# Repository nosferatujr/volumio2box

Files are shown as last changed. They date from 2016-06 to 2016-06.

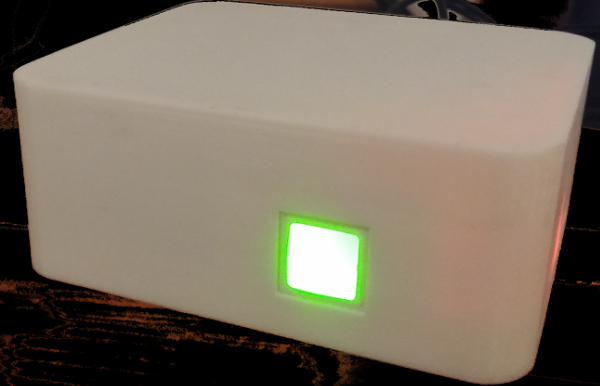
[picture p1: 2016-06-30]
photo.jpg

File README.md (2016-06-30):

PRinted box for RPi2 | HiFiBerry DAC+ | Proper poweroff (GPIO)  

You can find openscad files for the box on the BOX folder  
The Eagle PCB files on PCB folder  
The Pic microcontroller files, including the HEX on PowerController_PIC folder  
The off_button.py on the python folder. This file contain instruictions to be copied on the RPi, install dependencies, and run on the startup.  

    TO2:
    include photos for the conexion of all pcb inside the box
    put all this in a volumio plugin (pin configurable)

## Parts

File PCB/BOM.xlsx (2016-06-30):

Part | Value | Device | Package | Description | MF | OC_FARNELL | OC_NEWARK
C1 | 100n | C-EUC0805 | C0805 | CAPACITOR, European symbol
IC1 | 12F629 | PIC12F629SN | SO-08 | Data Sheet 8-Pin FLASH-Based 8-Bit CMOS Microcontrollers | MICROCHIP | 9759000 | 61K3433
JP1 | USB-RECEPTABLE | USB-RECEPTABLE | FCI-10103594-0001LF | USB Receptable |  | 2293752(farnell) (http://es.farnell.com/jsp/search/productdetail.jsp?CMP=i-ddd7-00001003&sku=2293752)
Q1, Q2 | AP4435GH | IRFR5305 | D-PAK_TO252AA | HEXFET Power MOSFET
R1, R3, R4, R7 | 2k2 | R-EU_R0805 | R0805 | RESISTOR, European symbol
R2 | 330 OHMIOS | R-EU_R0805 | R0805 | RESISTOR, European symbol
R5, R6 | 4k7 | R-EU_R0805 | R0805 | RESISTOR, European symbol
S1 | RF15L2 | RF15L2 | RF15L2 | RAFI SWITCH
SV1 |  | MA05-1 | FE05-1 | PINES MACHO |  | unknown | unknown
SV2 |  | MA04-1 | MA04-1 | PINES MACHO ACODADO |  | unknown | unknown
X1, X2 | 22-23-2021 | MA02-1 | 22-23-2021 | PINES MACHO ACODADO | MOLEX | 1462926 | 25C3832
T1, T2, T3 | BC848 | BC848 | SOT23 | NPN TRANSISTOR

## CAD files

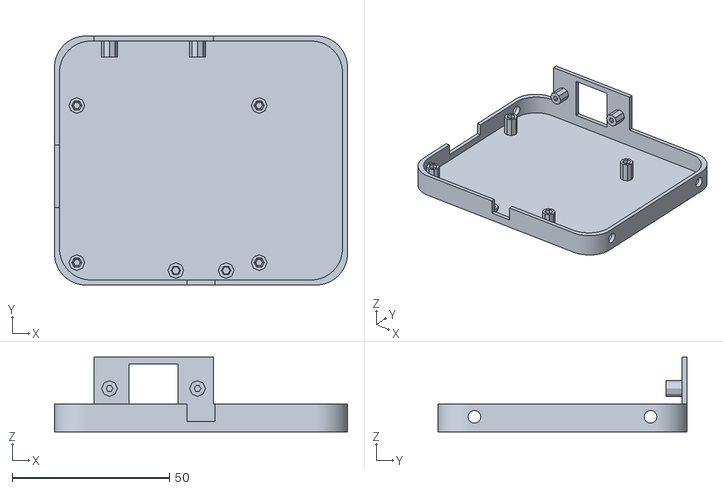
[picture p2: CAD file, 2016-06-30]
BOX/volumio_base.stl
93.2 x 79.2 x 23.8

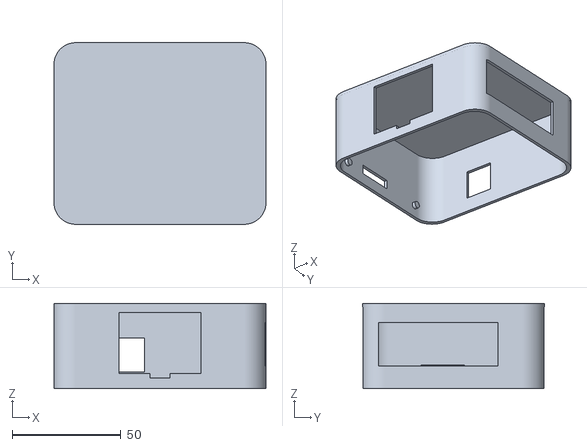
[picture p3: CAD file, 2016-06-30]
BOX/volumio_cover.stl
97.7 x 83.7 x 39.3

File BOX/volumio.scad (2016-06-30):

module fillet(r, h) {
        difference() {
            cube([r + 0.01, r + 0.01, h], center = true);
            translate([r/2, r/2, 0])
                cylinder(r = r, h = h + 1, $fn = 200,center = true);
        }
}

module torreta(h){
    translate([0,0 , h/2-.2 ])difference(){
  cylinder(  h-1.5 , 2.5,  2.5 ,true); 
  cylinder(  h , 1,  1.7 ,true);  
}
}

module soporte_pi (){
    
	translate([29, 25, 0])  torreta(9); 
	translate([-29, -25,  0 ])  torreta(9);  
	translate([-29, 25,  0])  torreta(9); 
	translate([29, -25,  0 ])  torreta(9);  
    
}
module torreta_puls(){
   	rotate([270,0,0]) translate([14, 0, 0])  torreta(7); 
	rotate([270,0,0]) translate([-14, 0,  0 ])  torreta(7);   
    
}

module soporte_usb (){
  translate([8, 0, 0 ])  torreta(3);
  translate([-8, 0, 0 ])  torreta(3);
}



module perfil(li,wi,h,t,r,tip){
    le=li+t*2;
    we=wi+t*2;
    
    module round(p){
        if (p==0){
        translate ([le/2-5,   we/2-5 ,0])rotate([180,180,0])fillet(r, h+1);
        translate ([(le/2*-1)+5,we/2-5,0])rotate([180,0,0])fillet(r, h+1);
        translate ([le/2-5,   (we/2*-1)+5,0])rotate([0,180,0])fillet(r, h+1);
        translate ([(le/2*-1)+5,(we/2*-1)+5,0])rotate([0,0,0])fillet(r, h+1);
        }
        else{     
        translate ([li/2-5,   wi/2-5 ,0])rotate([180,180,0])fillet(r, h+1);
        translate ([(li/2*-1)+5,wi/2-5,0])rotate([180,0,0])fillet(r, h+1);
        translate ([li/2-5,   (wi/2*-1)+5,0])rotate([0,180,0])fillet(r, h+1);
        translate ([(li/2*-1)+5,(wi/2*-1)+5,0])rotate([0,0,0])fillet(r, h+1);    
        }

}

    difference(){
    difference(){
    cube([le , we, h ] ,true );
    round(0);
    }
    if (tip!=1){
    difference(){
    cube([li , wi, h+1 ] ,true );
        round(1);
        }
    }
    }
}

module sop_pul(){
    difference(){
    cube([38,1.6,,20], center = true);  
     cube([15.5, 5,15.5  ] ,true );  
        }
     translate([0, -6.5, 0 ])torreta_puls();
    }

//tapa inferior
module tapa_i(){
  
 perfil(90,76,1.6,1.6,10,1);

 difference(){
 translate([0,0,4])perfil(90,76,8,1.6,10,0);
 translate([0, -40, 6 ])  cube([9,9,7], center = true);   
   rotate([0,90,0])  translate([-4,28,0]) cylinder(  105 , 2,  2 ,true, $fn=100); 
  rotate([0,90,0])  translate([-4,-28,0]) cylinder(  105 , 2,  2 ,true, $fn=100); 
      translate([ -15.5,38,11]) cube([18, 5,16 ] ,true ); 
     translate([ -48,-5,6]) cube([7, 20,5 ] ,true ); 
     }

 translate([-10.5, -7.5, 0])   soporte_pi ();
 translate([0, -35, 0 ])   soporte_usb();

   translate([-15.1, 38.8, 13. ]) sop_pul(); ;
}

// tapa superior
module tapa_s(){
    difference(){
 perfil(94.5,80.4,39,1.6,10,0);
  translate([0, -40, -11 ])  cube([9,9,7], center = true); 
  translate([47,-7,1]) cube([7,55,20], center = true);     
//pulsador
translate([-15,40,-4])    cube([15.5, 5,15.5  ] ,true );  
//sd      
 translate([ -48,-5,-11]) cube([7, 20,5 ] ,true );

// rear
translate([ 0,-40,1.5]) cube([38, 7,28 ] ,true );        
    }  
    

    
 translate([0,0,19]) perfil(94.5,80.5,1.6,1.6,10,1);
 rotate([0,90,0])  translate([13,28,47]) cylinder(  3 , 1.8,  1.8 ,true, $fn=100); 
 rotate([0,90,0])  translate([13,-28,47]) cylinder(  3 , 1.8,  1.8 ,true, $fn=100);
 rotate([0,90,0])  translate([13,28,-47]) cylinder(  3 , 1.8,  1.8 ,true, $fn=100); 
 rotate([0,90,0])  translate([13,-28,-47]) cylinder(  3 , 1.8,  1.8 ,true, $fn=100);
    
  
   
}
color("LimeGreen")tapa_i();
//translate([0,0,19])tapa_s(); //z:19 / 35

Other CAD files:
PowerController_PIC/pipower.X/dist/default/production/pipower.X.production.obj

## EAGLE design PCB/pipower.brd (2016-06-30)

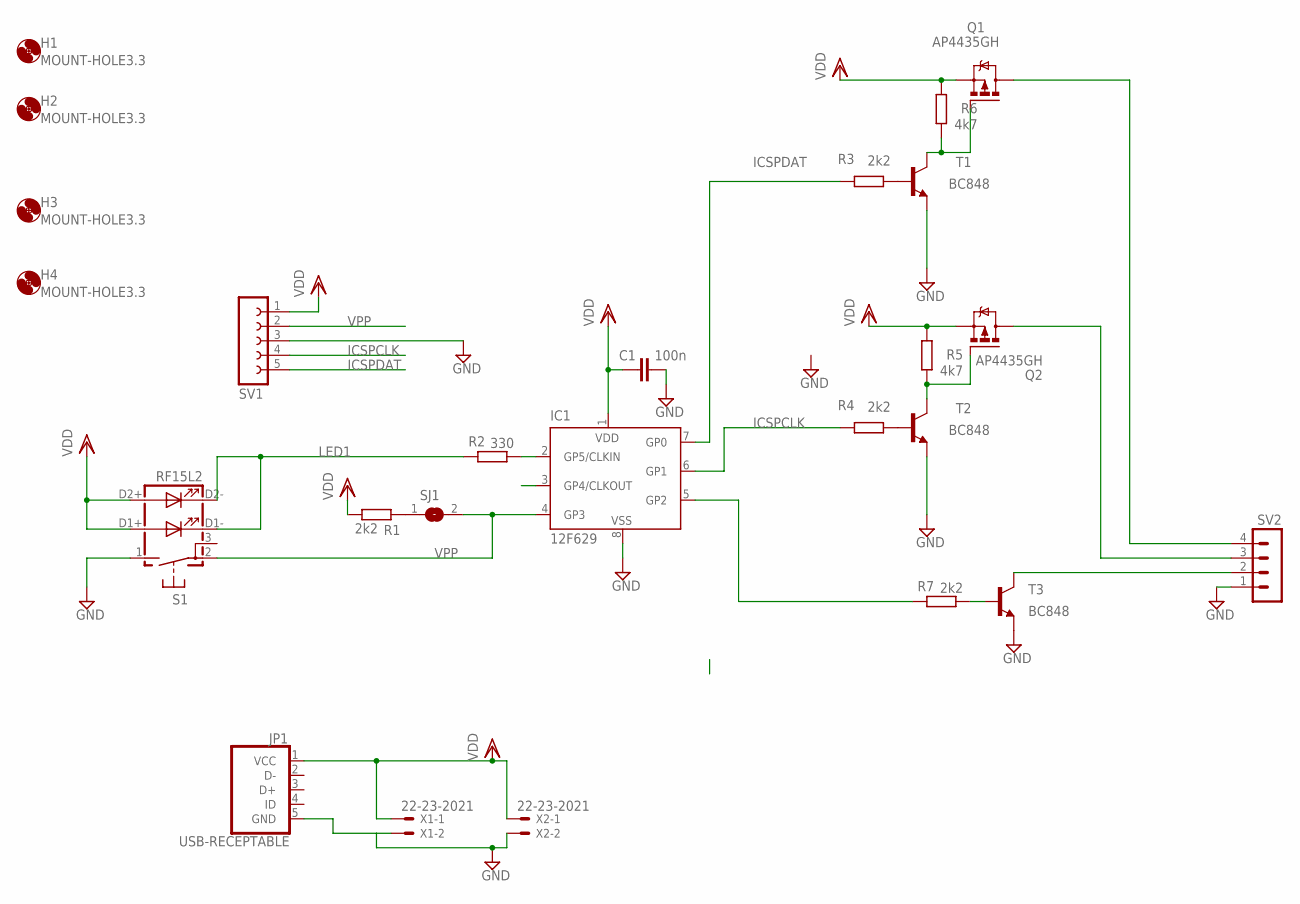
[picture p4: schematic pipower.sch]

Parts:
C1: 100n; C0805
H1, H2, H3, H4: MOUNT-HOLE3.3; 3,3
IC1: 12F629; SO-08; MPN PIC12F629-I/SN
JP1: USB-RECEPTABLE; FCI-10103594-0001LF
Q1, Q2: AP4435GH; D-PAK_TO252AA
R1, R3, R4, R7: 2k2; R0805
R2: 330; R0805
R5, R6: 4k7; R0805
S1: RF15L2
SJ1: SJ
SV1: FE05-1
SV2: MA04-1
T1, T2, T3: BC848; SOT23
X1, X2: 22-23-2021

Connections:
GND: C1.2, IC1.8 (VSS), JP1.5 (GND), S1.1 (S), SV1.3, SV2.1, T1.2 (E), T2.2 (E), T3.2 (E), X1.2, X2.2
ICSPCLK: IC1.6 (GP1), R4.2, SV1.4
ICSPDAT: IC1.7 (GP0), R3.2, SV1.5
LED1: R2.2, S1.D1- (C1), S1.D2- (C2)
unnamed: IC1.5 (GP2), R7.2
unnamed: Q1.4 (D), SV2.4
unnamed: Q2.1 (G), R5.1, T2.3 (C)
unnamed: R3.1, T1.1 (B)
unnamed: R1.2, SJ1.1
unnamed: R4.1, T2.1 (B)
unnamed: Q2.4 (D), SV2.3
unnamed: Q1.1 (G), R6.1, T1.3 (C)
unnamed: IC1.2 (GP5/CLKIN), R2.1
unnamed: SV2.2, T3.3 (C)
unnamed: R7.1, T3.1 (B)
VDD: C1.1, IC1.1 (VDD), JP1.1 (VCC), Q1.3 (S), Q2.3 (S), R1.1, R5.2, R6.2, S1.D1+ (A1), S1.D2+ (A2), SV1.1, X1.1, X2.1
VPP: IC1.4 (GP3), S1.2, SJ1.2, SV1.2

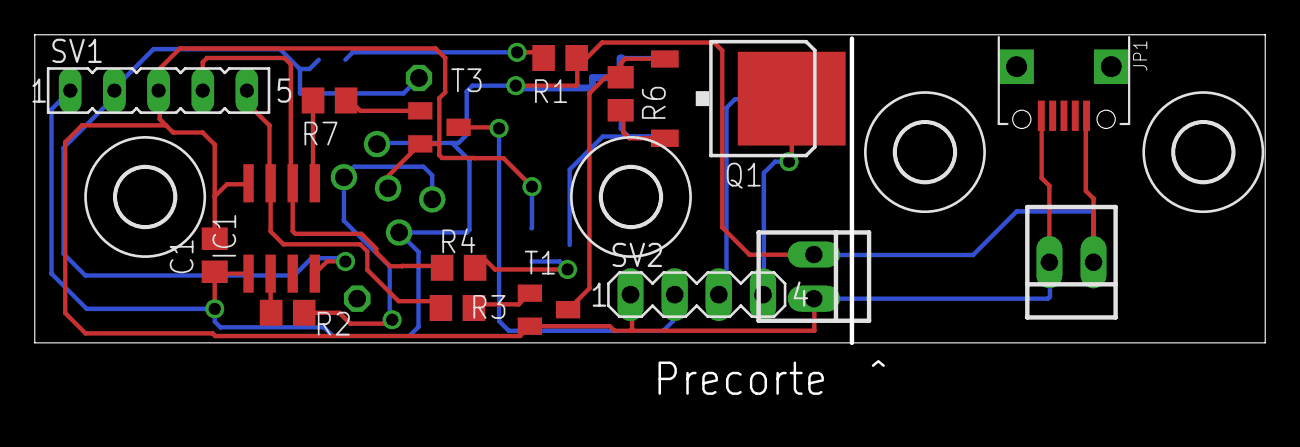
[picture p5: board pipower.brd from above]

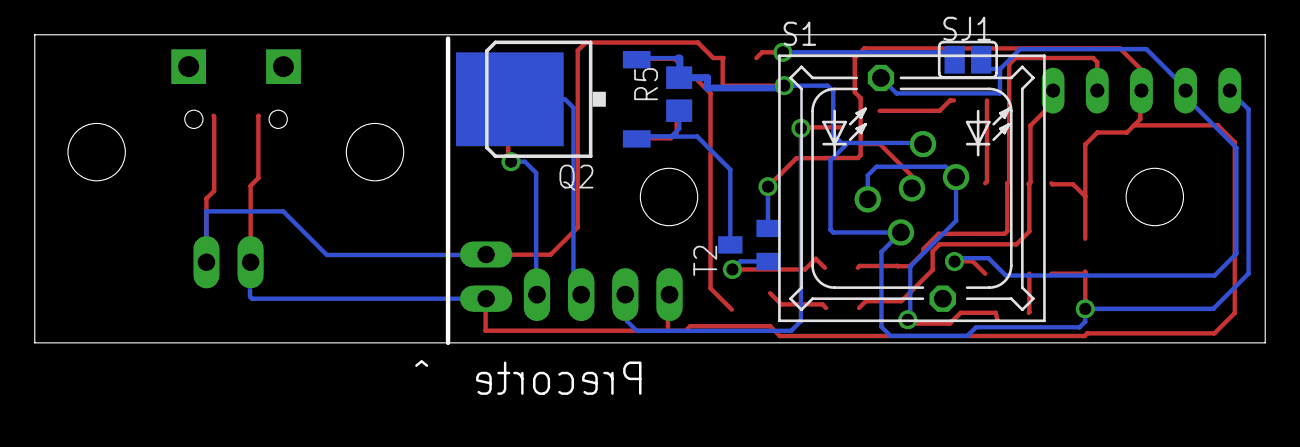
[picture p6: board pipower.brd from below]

Board: 2 copper layers, 70.8 x 17.7 mm, 25 parts (5 on the bottom side), 17 nets.

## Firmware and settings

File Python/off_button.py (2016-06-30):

#!/bin/python
#This script was authored by AndrewH7 and belongs to him (www.instructables.com/member/AndrewH7)
#You have permission to modify and use this script only for your own personal usage
#You do not have permission to redistribute this script as your own work
#Use this script at your own risk
#
#		INSTALL INSTRUCTIONS FOR VOLUMIO2 
#
#apt-get update
#apt-get install gcc python-dev python-pip i2c-tools libi2c-dev python-smbus 
#pip install RPi.GPIO 
#
#put this file on /home/pi/off_button.py
#
#sudo nano /etc/rc.local
#          before exit 0; add   python /home/pi/off_button.py
#
#

import RPi.GPIO as GPIO
import os

#
# We chose GPIO16 beacuse is unused by HiFiBerry DAC+, Digi+ and Amp+ (i2C and gpio 18 to 21)
#It's very important the pin is an input to avoid short-circuits
#The pull-up resistor means the pin is high by default

gpio_pin_number=16

GPIO.setmode(GPIO.BCM)

GPIO.setup(gpio_pin_number, GPIO.IN, pull_up_down=GPIO.PUD_UP)


try:
    #Use falling edge detection to see if pin is pulled 
    #low to avoid repeated polling
    GPIO.wait_for_edge(gpio_pin_number, GPIO.FALLING)
    #Send command to system to shutdown
    os.system("sudo shutdown -h now")
    
except:
    pass

#Revert all GPIO pins to their normal states (i.e. input = safe)
GPIO.cleanup()

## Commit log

2016-06-30 the openscad files
    [volumio.scad, volumio_base.stl, volumio_cover.stl]
2016-06-30 added Eagle Pcb files
    [BOM.xlsx, pipower.brd, pipower.sch]
2016-06-30 PiC files
    [pipower.X.production.obj]
